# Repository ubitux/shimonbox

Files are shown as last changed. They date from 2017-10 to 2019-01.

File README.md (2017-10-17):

ShimonBox
=========

ShimonBox is an [OpenSCAD][openscad] project aiming at providing
semi-automatically generated 3D printable cases for development boards.

See [pkh.me introduction blog post][blog-post] for more information.

[openscad]: http://www.openscad.org
[blog-post]: http://blog.pkh.me/p/24-making-development-board-cases-with-shimonbox.html

Supported boards
----------------

| Board name | Preview |
| --- | --- |
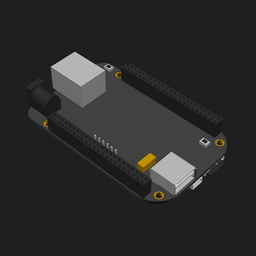
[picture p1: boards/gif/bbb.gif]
| [BeagleBone Black](boards/bbb.scad) |  |
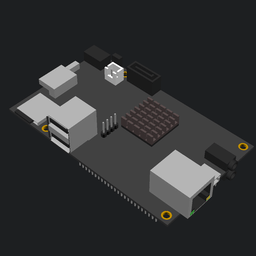
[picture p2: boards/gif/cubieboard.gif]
Cubieboard
| [Cubieboard](boards/cubieboard.scad) |  |
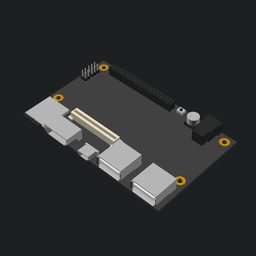
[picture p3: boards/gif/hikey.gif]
Hikey
| [Hikey (LeMaker)](boards/hikey.scad) |  |
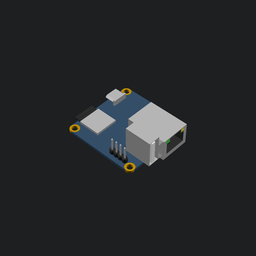
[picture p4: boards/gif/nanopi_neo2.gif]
NanoPi Neo 2
| [NanoPi Neo 2](boards/nanopi_neo2.scad) |  |
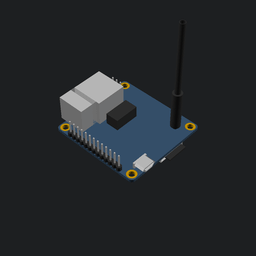
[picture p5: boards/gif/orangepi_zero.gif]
Orange Pi Zero
| [Orange Pi Zero](boards/orangepi_zero.scad)  |   |
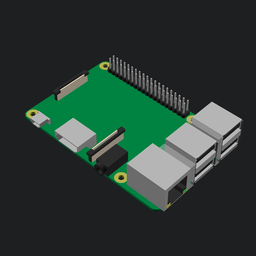
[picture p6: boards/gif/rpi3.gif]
| [Raspberry Pi 3](boards/rpi3.scad) |  |

Corresponding cases
-------------------

| Board name | Preview | Status |
| --- | --- | --- |
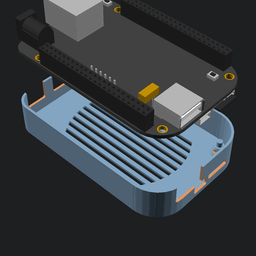
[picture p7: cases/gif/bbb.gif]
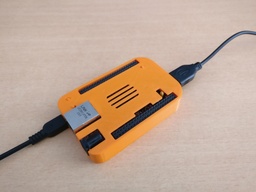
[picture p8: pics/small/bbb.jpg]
| [BeagleBone Black](cases/bbb.scad) |  | [VERIFIED](pics/bbb.jpg):<br /> |
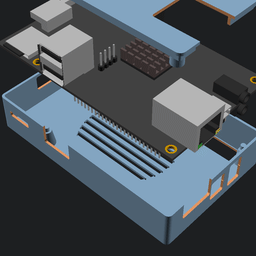
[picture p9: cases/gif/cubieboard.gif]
Cubieboard
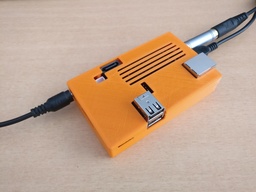
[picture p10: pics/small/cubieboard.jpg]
Cubieboard
| [Cubieboard](cases/cubieboard.scad) |  | [VERIFIED](pics/cubieboard.jpg):<br /> |
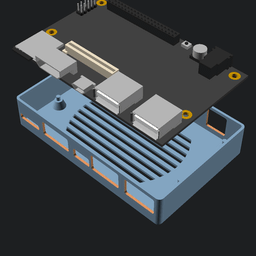
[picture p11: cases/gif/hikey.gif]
Hikey
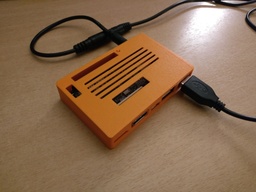
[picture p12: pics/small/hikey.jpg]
Hikey
| [Hikey (LeMaker)](cases/hikey.scad) |  | [VERIFIED](pics/hikey.jpg):<br /> |
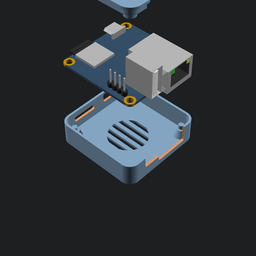
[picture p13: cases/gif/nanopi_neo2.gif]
NanoPi Neo 2
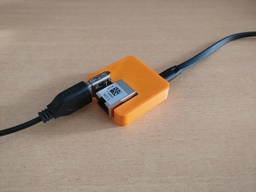
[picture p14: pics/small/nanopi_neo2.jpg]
NanoPi Neo 2
| [NanoPi Neo 2](cases/nanopi_neo2.scad) |  | [VERIFIED](pics/nanopi_neo2.jpg):<br /> |
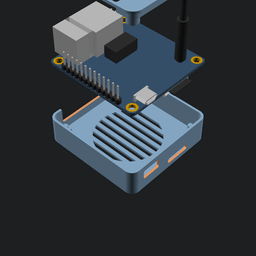
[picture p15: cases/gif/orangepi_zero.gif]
Orange Pi Zero
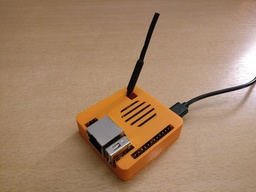
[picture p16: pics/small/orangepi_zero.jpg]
Orange Pi Zero
| [Orange Pi Zero](cases/orangepi_zero.scad) |  | [VERIFIED](pics/orangepi_zero.jpg):<br /> |
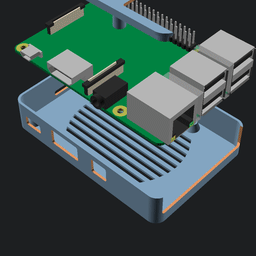
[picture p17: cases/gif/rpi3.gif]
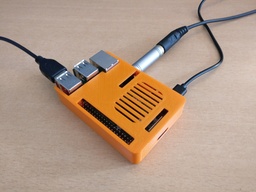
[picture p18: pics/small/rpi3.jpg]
| [Raspberry Pi 3](cases/rpi3.scad) |  | [VERIFIED](pics/rpi3.jpg):<br /> |

Usage
-----

To make all the `.stl` files, run `make`. The resulting files will be found in
the [cases/](cases) directory.

If you're looking at building individual parts, you can use `make
cases/<board>-<part>.stl` where `<board>` is the board name and `<part>` is the
part you want to build (`bottom`, `top`, or `button`).

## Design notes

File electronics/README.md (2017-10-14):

| Category | Preview |
| --- | --- |
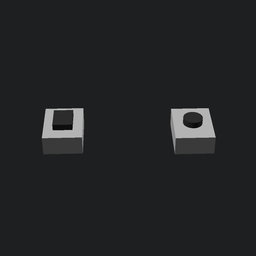
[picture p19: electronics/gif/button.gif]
Buttons
| Buttons |  |
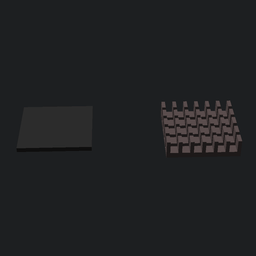
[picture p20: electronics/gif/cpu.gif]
CPU
| CPU |  |
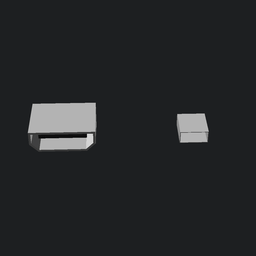
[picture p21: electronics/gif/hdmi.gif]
HDMI
| HDMI |  |
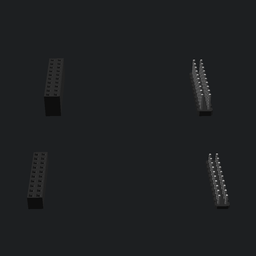
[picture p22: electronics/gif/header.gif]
headers
| Pin and Female Headers  |  |
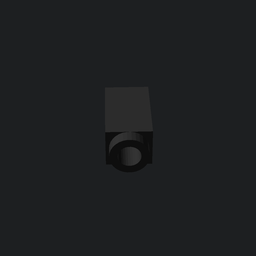
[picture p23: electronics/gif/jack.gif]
jack
| Jack |  |
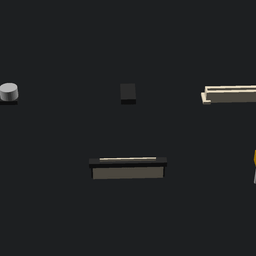
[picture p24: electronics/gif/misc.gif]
Misc
| Miscleanous stuff |  |
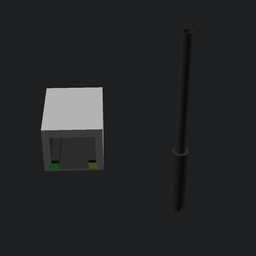
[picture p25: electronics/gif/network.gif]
Network
| Network |   |
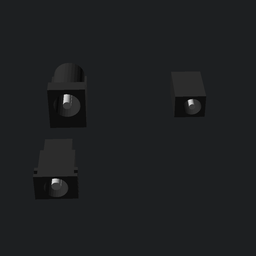
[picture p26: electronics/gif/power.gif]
Power
| Power |  |
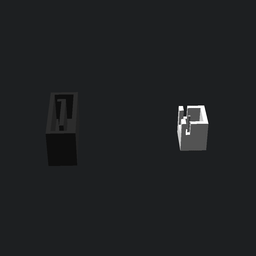
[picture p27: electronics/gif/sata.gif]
SATA
| SATA |  |
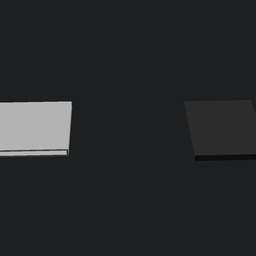
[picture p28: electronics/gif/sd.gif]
| SD |  |
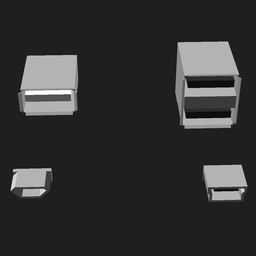
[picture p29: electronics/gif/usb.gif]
USB
| USB |  |

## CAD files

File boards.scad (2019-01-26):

// Copyright (c) 2017 Clément Bœsch <u pkh.me>
//
// Permission to use, copy, modify, and distribute this software for any
// purpose with or without fee is hereby granted, provided that the above
// copyright notice and this permission notice appear in all copies.
//
// THE SOFTWARE IS PROVIDED "AS IS" AND THE AUTHOR DISCLAIMS ALL WARRANTIES
// WITH REGARD TO THIS SOFTWARE INCLUDING ALL IMPLIED WARRANTIES OF
// MERCHANTABILITY AND FITNESS. IN NO EVENT SHALL THE AUTHOR BE LIABLE FOR
// ANY SPECIAL, DIRECT, INDIRECT, OR CONSEQUENTIAL DAMAGES OR ANY DAMAGES
// WHATSOEVER RESULTING FROM LOSS OF USE, DATA OR PROFITS, WHETHER IN AN
// ACTION OF CONTRACT, NEGLIGENCE OR OTHER TORTIOUS ACTION, ARISING OUT OF
// OR IN CONNECTION WITH THE USE OR PERFORMANCE OF THIS SOFTWARE.

include <globals.scad>

use <utils.scad>

use <boards/bbb.scad>
use <boards/cubieboard.scad>
use <boards/hikey.scad>
use <boards/nanopi_neo2.scad>
use <boards/orangepi_zero.scad>
use <boards/rpi3.scad>
use <boards/wemos_esp8266.scad>

boards = [
    ["bbb",             beaglebone_black_info()],
    ["cubieboard",      cubieboard_info()],
    ["hikey",           hikey_info()],
    ["nanopi_neo2",     nanopi_neo2_info()],
    ["orangepi_zero",   orangepi_zero_info()],
    ["rpi3",            raspberry_pi_3_info()],
    ["wemos_esp8266",   wemos_esp8266_info()],
];

module boards_get_plate_2d(id) {
    filter(id) {
        beaglebone_black_plate_2d();
        cubieboard_plate_2d();
        hikey_plate_2d();
        nanopi_neo2_plate_2d();
        orangepi_zero_plate_2d();
        raspberry_pi_3_plate_2d();
        wemos_esp8266_plate_2d();
    }
}

module boards_get_board(id) {
    filter(id) {
        beaglebone_black();
        cubieboard();
        hikey();
        nanopi_neo2();
        orangepi_zero();
        raspberry_pi_3();
        wemos_esp8266();
    }
}

function boards_get_id(name) = search([name], boards)[0];
function boards_get_info(id) = boards[id][1];

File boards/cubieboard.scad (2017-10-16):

// Copyright (c) 2017 Clément Bœsch <u pkh.me>
//
// Permission to use, copy, modify, and distribute this software for any
// purpose with or without fee is hereby granted, provided that the above
// copyright notice and this permission notice appear in all copies.
//
// THE SOFTWARE IS PROVIDED "AS IS" AND THE AUTHOR DISCLAIMS ALL WARRANTIES
// WITH REGARD TO THIS SOFTWARE INCLUDING ALL IMPLIED WARRANTIES OF
// MERCHANTABILITY AND FITNESS. IN NO EVENT SHALL THE AUTHOR BE LIABLE FOR
// ANY SPECIAL, DIRECT, INDIRECT, OR CONSEQUENTIAL DAMAGES OR ANY DAMAGES
// WHATSOEVER RESULTING FROM LOSS OF USE, DATA OR PROFITS, WHETHER IN AN
// ACTION OF CONTRACT, NEGLIGENCE OR OTHER TORTIOUS ACTION, ARISING OUT OF
// OR IN CONNECTION WITH THE USE OR PERFORMANCE OF THIS SOFTWARE.

include <../globals.scad>

use <../case.scad>
use <../utils.scad>
use <../electronics/button.scad>
use <../electronics/cpu.scad>
use <../electronics/hdmi.scad>
use <../electronics/header.scad>
use <../electronics/jack.scad>
use <../electronics/misc.scad>
use <../electronics/network.scad>
use <../electronics/power.scad>
use <../electronics/sata.scad>
use <../electronics/sd.scad>
use <../electronics/usb.scad>


board_dim = [100, 60, 1.25];


/* Plate holes */
hole_d = 3;
hole_orig = [board_dim[0], board_dim[1]] * -.5;
ring_off = 1.5;
hole_pad = 3.5;
hole_pad_t = [1,-1]*hole_pad;
holes_pos = [for (y=hole_pad_t+[   0, board_dim[1]],
                  x=hole_pad_t+[19.5, board_dim[0]]) hole_orig + [x, y]];


/* Components bounding box dimensions */
cpu_dim         = [   19,   19, 1.25];
cpurad_dim      = [   19,   19,    5];
ethernet_dim    = [   21,   16, 13.5];
fel_dim         = [  3.5,    7,  3.5];
gpio_dim        = [   50,    6,    6];
hdmi_dim        = [11.25,   15,    6];
ir_dim          = [  3.5,    5,    7];
jack_dim        = [   14,  6.5,    5];
microsdcard_dim = [   15,   11,    1];
microsdslot_dim = [14.75,   15,    2];
otg_dim         = [    9,    7,    4];
power_dim       = [   12,  7.5,    6];
powerbtn_dim    = [  3.5,    7,  3.5];
sata_5v_dim     = [  7.5,    6,  7.5];
sata_data_dim   = [   17,  6.5,    9];
serial_dim      = [10.25,  2.5,  8.5];
usbx2_dim       = [ 17.5, 14.5,   16];

pwrhdmi_dim     = [3.5, 2, 3.5]; // cleanup box

module cubieboard_plate_2d() {
    plate_2d(board_dim[0], board_dim[1]);
}

comp_info = [
    /* info function        box dimensions   comp-corner rotate  board-corner    position  */
    [button_drill_info(),   fel_dim,         [-1,-1, 1], [0,1,0], [ 1,-1,-1], [   0,26.5,   0]],
    [button_drill_info(),   powerbtn_dim,    [-1, 1, 1], [0,3,0], [-1, 1, 1], [ -.5, -16,   0]],
    [cpu_info(),            cpu_dim,         [-1,-1,-1], [0,0,0], [-1,-1, 1], [47.5,  28,   0]],
    [cpurad_info(),         cpurad_dim,      [-1,-1,-1], [0,0,0], [-1,-1, 1], [47.5,  28,1.25]],
    [ethernet_info(),       ethernet_dim,    [ 1,-1,-1], [0,0,0], [ 1,-1, 1], [   4,   8,   0]],
    [hdmi_info(),           hdmi_dim,        [ 1, 1,-1], [0,0,2], [-1,-1, 1], [ -.5,  20,   0]],
    [ir_info(),             ir_dim,          [-1,-1,-1], [0,0,3], [-1, 1, 1], [13.5,  .5,   0]],
    [jack_info(),           jack_dim,        [ 1,-1, 1], [0,0,0], [ 1,-1,-1], [   2,  39,   0]], // bottom
    [jack_info(),           jack_dim,        [ 1,-1,-1], [0,0,0], [ 1,-1, 1], [   2,  39,   0]], // top
    [microsdcard_info(),    microsdcard_dim, [ 1,-1,-1], [0,0,3], [-1,-1, 1], [   5, -.5,   1]],
    [microsdslot_info(),    microsdslot_dim, [ 1,-1,-1], [0,0,3], [-1,-1, 1], [   4,1.75,   0]],
    [miniusb_info(),        otg_dim,         [ 1,-1,-1], [0,0,0], [ 1,-1, 1], [   1,26.5,   0]],
    [pin_header_info(),     gpio_dim,        [ 1, 1,-1], [2,0,0], [ 1,-1,-1], [  -6,  .5,   0]],
    [pin_header_info(),     gpio_dim,        [ 1,-1,-1], [2,0,0], [ 1, 1,-1], [  -6, -.5,   0]],
    [pin_header_info(),     serial_dim,      [-1, 1,-1], [0,0,1], [-1,-1, 1], [44.5,  17,   0]],
    [power_cubie_info(),    power_dim,       [ 1,-1,-1], [0,0,2], [-1, 1, 1], [   0,-2.5,   0]],
    [sata_5v_info(),        sata_5v_dim,     [-1,-1,-1], [0,0,0], [-1,-1, 1], [  18,  47,   0]],
    [sata_data_info(),      sata_data_dim,   [ 1,-1,-1], [0,0,2], [-1, 1, 1], [  27,   0,   0]],
    [usbx2_info(),          usbx2_dim,       [ 1,-1,-1], [0,0,3], [-1,-1, 1], [  29, -.5,   0]],

    [unknown_drill_info(),  pwrhdmi_dim,     [ 1, 1,-1], [0,0,2], [-1,-1, 1], [ -.5,  35,   0]],
];

module cubieboard() {
    // TODO: ring $fn=8
    extrude_plate(board_dim[2], holes_pos, hole_d, ring_off)
        cubieboard_plate_2d();

    set_components(board_dim, comp_info) {
        button(dim=fel_dim);
        button(dim=powerbtn_dim);
        cpu(dim=cpu_dim);
        cpurad(dim=cpurad_dim);
        ethernet(dim=ethernet_dim);
        hdmi(dim=hdmi_dim);
        ir(dim=ir_dim);
        jack(dim=jack_dim);
        jack(dim=jack_dim);
        microsdcard(dim=microsdcard_dim);
        microsdslot(dim=microsdslot_dim);
        miniusb(dim=otg_dim);
        pin_header_pitch200(dim=gpio_dim, n=24, m=2);
        pin_header_pitch200(dim=gpio_dim, n=24, m=2);
        pin_header_pitch254(dim=serial_dim, n=4, m=1);
        power_cubie(dim=power_dim);
        sata_5v(dim=sata_5v_dim);
        sata_data(dim=sata_data_dim);
        usbx2(dim=usbx2_dim);

        %cube(pwrhdmi_dim, center=true);
    }
}

function cubieboard_info() = [
    ["board_dim",  board_dim],
    ["components", comp_info],
    ["holes_d",    hole_d],
    ["holes_pos",  holes_pos],
];

demo_board(board_dim) {
    cubieboard();
    *#bounding_box(board_dim, comp_info);
}

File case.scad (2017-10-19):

// Copyright (c) 2017 Clément Bœsch <u pkh.me>
//
// Permission to use, copy, modify, and distribute this software for any
// purpose with or without fee is hereby granted, provided that the above
// copyright notice and this permission notice appear in all copies.
//
// THE SOFTWARE IS PROVIDED "AS IS" AND THE AUTHOR DISCLAIMS ALL WARRANTIES
// WITH REGARD TO THIS SOFTWARE INCLUDING ALL IMPLIED WARRANTIES OF
// MERCHANTABILITY AND FITNESS. IN NO EVENT SHALL THE AUTHOR BE LIABLE FOR
// ANY SPECIAL, DIRECT, INDIRECT, OR CONSEQUENTIAL DAMAGES OR ANY DAMAGES
// WHATSOEVER RESULTING FROM LOSS OF USE, DATA OR PROFITS, WHETHER IN AN
// ACTION OF CONTRACT, NEGLIGENCE OR OTHER TORTIOUS ACTION, ARISING OUT OF
// OR IN CONNECTION WITH THE USE OR PERFORMANCE OF THIS SOFTWARE.

include <globals.scad>
include <boards.scad>
use <utils.scad>

case_thickness  = 1.2;
breath_padding  = 1;
contact_padding = .2;

/* Centered top of the buttons looking at the sky, and their dimensions */
function _get_buttons_pushers_pos_dim(board_dim, cfg, info) = [
    let(comp_info_list = map_get(info, "components"))

    for (comp_info = comp_info_list)
        let(meta         = comp_info[0],
            dim          = comp_info[1],
            corner_comp  = comp_info[2],
            rot          = comp_info[3],
            corner_board = comp_info[4],
            position     = comp_info[5],
            category     = map_get(meta, "category"))

        if (category == "button" && [rot[0], rot[1]] == [0, 0])
            let(rz             = comp_info[3][2] * 90,
                rotm           = [[cos(rz),sin(rz),0], [-sin(rz),cos(rz),0], [0,0,1]],
                corner_pos     = pmul(corner_comp, dim) * -.5,
                postrotate_pos = corner_pos * rotm,
                board_pos      = pmul(corner_board, board_dim) * .5,
                centered_pos   = postrotate_pos + position + board_pos,
                pos            = centered_pos + [0, 0, dim[2]/2])

            [pos, dim]
];

module _vents(vents, w=2.1) {
    if (vents != []) {
        dim = map_get(vents, "dim");
        pos = map_get(vents, "pos");

        length = dim[1];
        n_segments = floor(length / w);
        n_vents    = ceil(n_segments / 2);
        n_segwalls = n_segments - n_vents;
        n_walls    = n_segwalls - (n_segwalls == n_vents ? 1 : 0);
        off        = (length - (n_vents+n_walls)*w) / 2;
        start      = -length/2 + off + w/2;
        translate(pos) {
            intersection() {
                circle(d=max(dim), center=true);
                for (i = [0:n_vents-1])
                    translate([0, start + i*w*2])
                        square([dim[0], w], center=true);
            }
        }
    }
}

module _case_plate_2d(case_id) {
    offset(r=case_thickness + breath_padding + _delta)
        boards_get_plate_2d(case_id);
}

module _case_top(case_id, cfg, info, z_offset, buttons_pos_dim) {
    top_border_height = 3; // XXX: maybe auto to (max_z+bp)/2 or /3?

    board_dim = map_get(info, "board_dim");
    comp_info = map_get(info, "components");
    holes_d   = map_get(info, "holes_d");
    holes_pos = map_get(info, "holes_pos");

    vents = map_get(map_get(cfg, "vents"), "top");

    difference() {
        union() {
            // plate
            linear_extrude(height=case_thickness, center=true, convexity=2) {
                difference() {
                    _case_plate_2d(case_id);
                    _vents(vents);
                }
            }

            // borders
            translate([0, 0, -case_thickness/2 - top_border_height]) {
                linear_extrude(height=top_border_height, convexity=2) {
                    difference() {
                        offset(r=breath_padding - contact_padding)
                            boards_get_plate_2d(case_id);
                        offset(r=breath_padding - contact_padding - case_thickness)
                            boards_get_plate_2d(case_id);
                    }
                }
            }

            // board carriers clippers
            h = map_get(cfg, "max_z") + breath_padding - contact_padding;
            for(pos = holes_pos) {
                translate([pos[0], pos[1], -(h+case_thickness)/2]) {
                    difference() {
                        cylinder(h=h, d=holes_d+2, center=true);
                        cylinder(h=h+_delta, d=holes_d, center=true);
                    }
                }
            }

            // button pushers borders
            for (button_pos_dim = buttons_pos_dim) {
                button_pos = button_pos_dim[0];
                button_dim = button_pos_dim[1];
                h = top_border_height;
                d = _get_button_pusher_d(button_dim) + case_thickness*2;
                translate([button_pos[0], button_pos[1], -case_thickness/2-h])
                    cylinder(h=h, d=d);
            }
        }

        translate([0, 0, -z_offset])
            bounding_box(board_dim, comp_info, breath_padding);

        for (button_pos_dim = buttons_pos_dim) {
            button_pos = button_pos_dim[0];
            button_dim = button_pos_dim[1];
            h = top_border_height + case_thickness + _delta;
            d = _get_button_pusher_d(button_dim) + contact_padding;
            translate([button_pos[0], button_pos[1], case_thickness/2-h+_delta/2])
                cylinder(h=h, d=d);
        }
    }
}

module _case_bottom(case_id, cfg, info, z_offset, bottom_border_h) {
    board_dim = map_get(info, "board_dim");
    comp_info = map_get(info, "components");
    holes_d   = map_get(info, "holes_d");
    holes_pos = map_get(info, "holes_pos");

    vents = map_get(map_get(cfg, "vents"), "bottom");

    difference() {
        union() {
            // plate
            linear_extrude(height=case_thickness, center=true) {
                difference() {
                    _case_plate_2d(case_id);
                    _vents(vents);
                }
            }

            // borders
            translate([0, 0, case_thickness/2]) {
                linear_extrude(height=bottom_border_h, convexity=2) {
                    difference() {
                        _case_plate_2d(case_id);
                        offset(r=breath_padding + _delta)
                            boards_get_plate_2d(case_id);
                    }
                }
            }

            // board carriers
            carriers_base_h = -z_offset - board_dim[2]/2 - case_thickness/2;
            for(pos = holes_pos) {
                translate([pos[0], pos[1], case_thickness/2]) {
                    l1 = carriers_base_h;
                    l  = carriers_base_h + board_dim[2] + 1;
                    w0 = holes_d/2 - contact_padding;
                    w1 = w0 + 1;
                    w2 = w0 + 2.5;
                    rotate_extrude()
                        polygon([[0, 0], [w2, 0], [w1, l1], [w0, l1], [w0, l], [0, l]]);
                }
            }
        }
        translate([0, 0, -z_offset])
            bounding_box(board_dim, comp_info, breath_padding);
    }

}

module _button_pushers(board_dim, cfg, info, buttons_pos_dim) {
    for (button_pos_dim = buttons_pos_dim) {
        button_pos = button_pos_dim[0];
        button_dim = button_pos_dim[1];
        translate(button_pos) {
            h = _get_button_pusher_base_h(cfg) - button_dim[2];
            d = _get_button_pusher_d(button_dim);
            cylinder(d=d, h=d/2);
            cylinder(d=2*d/3, h=h);
        }
    }
}

function _get_button_pusher_base_h(info) =
    map_get(info, "max_z") + breath_padding + case_thickness + 1;

function _get_button_pusher_d(button_dim) =
    max(min(button_dim[0], button_dim[1]), 3.5);

module case(name, cfg, mode="demo") {
    case_id = boards_get_id(name);
    info = boards_get_info(case_id);
    comp_info = map_get(info, "components");

    // TODO: find min_z and max_z based on the comp list when not provided
    min_z = map_get(cfg, "min_z");
    max_z = map_get(cfg, "max_z");

    board_dim = map_get(info, "board_dim");
    board_h = board_dim[2];

    bottom_border_h = min_z + max_z + breath_padding*2 + board_h;

    z_offset_base   = board_h/2 + breath_padding + case_thickness/2;
    z_offset_bottom = -z_offset_base - min_z;
    z_offset_top    =  z_offset_base + max_z;

    case_pos_bottom = [0, 0, z_offset_bottom];
    case_pos_top    = [0, 0, z_offset_top];

    buttons_pos_dim = _get_buttons_pushers_pos_dim(board_dim, cfg, info);
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

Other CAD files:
cases/cubieboard.scad
boards/bbb.scad
boards/hikey.scad
boards/nanopi_neo2.scad
boards/orangepi_zero.scad
boards/rpi3.scad
boards/wemos_esp8266.scad
cases/bbb.scad
cases/hikey.scad
cases/nanopi_neo2.scad
cases/orangepi_zero.scad
cases/rpi3.scad
cases/wemos_esp8266.scad
electronics/_internal.scad
electronics/button.scad
electronics/cpu.scad
electronics/hdmi.scad
electronics/header.scad
electronics/jack.scad
electronics/misc.scad
electronics/network.scad
electronics/power.scad
electronics/sata.scad
electronics/sd.scad
electronics/usb.scad
globals.scad
utils.scad

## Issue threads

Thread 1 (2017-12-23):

Add Pine64 board support

dragetd, 2017-12-23:
I am working on adding the specs for the pine64 board.

ubitux, 2017-12-25:
Cool, I don't have that one :)

I've let this project on hold due to other projects taking over, and also because I'm waiting for kernel 4.15 before I can migrate my current odroid-c2 to the nanopi neo 2 (they need 4.15 for the ethernet support) and then design its board.

dragetd, 2017-12-25:
I have an odroid Zero, RPi 1, RPi Zero and eventually a few others to add. :)

Tho kind of busy with things, might take a little before I get to all of these. And I am still wondering if things could be simplified a little.

ubitux, 2017-12-25:
I have the RPi 1 on my TODO list, not sure how long it will take, please leave it to me ;)

dragetd, 2017-12-26:
Sure, I'll leave the RPi1 to you. :) But I might give pi zero a shot, ok? :)

Concerning the Pine64, this is how far I am right now: https://github.com/dragetd/shimonbox/tree/patch_pine64_b

It still lacks several things:

- [ ] Board color
- [ ] GPIO Header x2
- [ ] Expansion Header
- [ ] LCD/Camera bus
- [ ] (Optional) Reset-Button
- [ ] (Optional) LED holes
- [ ] Picture of printed case

I did print the current version and it worked pretty well. It had very minor asymmetries and the 'worst' thing were the mounting holes slightly off (required some force to insert there). But I corrected these things and it should print just fine. Tho before printing another one, I would like to tackle some of the TODOs.

ubitux, 2017-12-26:
> But I might give pi zero a shot, ok? :)

Sure, I don't have that one

> Board color

see `clr` parameter in `extrude_plate()`

> GPIO Header x2

Female and pin headers in `electronics/header.scad` don't do the trick?

dragetd, 2017-12-26:
Yes it does. I was just too lazy, since I do not need those headers for the case I just printed. :P I am busy with other things… once I got my other projcets sorted, I will continue here. Just thought I could already share the progress. :)

dragetd, 2019-02-27:
Please excuse my radio silence. #life happened. :( I hope I will eventually come back to progressing on this - but if anyone else wants to continue the work, please feel free!

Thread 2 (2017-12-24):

Reduce redudancy when defining boards

dragetd, 2017-12-24:
Hey there,

currently adding one or two more boards. While doing this, I also thought about writing a little doc about how to add new boards.

I noticed that I had to put the board name at several places… like defining the base plate it needs an individual name. Then again I also need to add the board to the top-level file boards.scad.

I did not yet read through all the files completely, thus I do not fully understand why it needs to be defined at so many places. Maybe OpenSCAD has some functions to redcuce the redundancy at some points, thus making it easier to add new ones. When I find more specifig things, I will report back to this issue. :-)

ubitux, 2017-12-25:
The OpenSCAD language is pretty limited unfortunately. I tried my best to reduce the need for redundancy without the use of an external language, but typically modules and functions can not be mapped to each other (like, you can't have a function that points to a module). If you find a way of simplifying further, patches welcome.

Also, shimonbox provides boards and cases and you want to be able to use the board model only, without the case.

I should have written a doc on adding a board yes... so far only the blog post gives an overview (http://blog.pkh.me/p/24-making-development-board-cases-with-shimonbox.html)

Here is a quick & dirty howto:

- create `boards/<board>.scad` following other `.scad` files in the same directory. This `.scad` is directly open-able with openscad.
- if necessary, add the electronic components in `electronics/<xxx>.scad`. The `.scad` files are directly open-able with openscad.
- register the board in `boards.scad` (include of `boards/<board>.scad`, mapping array to the info function, and the 2 modules entries)
- create `cases/<board>.scad` following other `.scad` files in the same directory (this one should be pretty simple). This `.scad` is directly open-able with openscad.
- if your board has button pushers, you want to register it in `cases/Makefile` (`BOARDS_WITH_BUTTON_PUSHERS`)
- `make -j$(nproc) gif` will generate the gif (it may take some time)

Feel free to correct me if I forgot something.

dragetd, 2017-12-26:
Yes, I see why you did many things like you did. And I really agree with you on what you wrote in the blog post: OpenSCAD really needs some dev power to improve on a few things. =/

So I will close this issue.

Concerning the contributing guidelines: Will open a new issue once I got around to writing a first version. :)

Closed 2017-12-26.

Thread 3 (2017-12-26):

Add little notch/groove between bottom/top lid?

dragetd, 2017-12-26:
My first print in #1 fits pretty tightly, since the bottom case flexes a tiny little bit because my PCB holes were ~0.2mm off (fixed in my current branch).

But generally, the top part is just 'resting' on the bottom part. What do you think about adding a little groove around the lip that would click into the bottom part?

I would give it a try to modify the case.scad and use a 0.5mm cylinder + a cut on the bottom side that makes the two halves clip together. Any thoughts on this?

ubitux, 2017-12-26:
Mmh. Have you tried to reduced `contact_padding` in `case.scad`? My printer is pretty cheap, so I had to use a `>0` value for parts that are supposed to touch. It could be made configurable by the user, but since I could test the print only on my printer, some settings might be more appropriate than other for other printers.

dragetd, 2018-01-13:
It fits pretty neatly. But it could have a satisfying *click*. =D

Tho, this idea, just like the others are postponed for me till February. If anyone else wants to have a go before me, feel free!

ubitux, 2018-01-13:
A previous version was actually designed with a complex clicking system. Unfortunately, given how thin the whole box and how precise my printer was, it was meaningless complexity. Basically, it either had no effect in the best case, or distorting the whole thing (because the clip wouldn't fit in the mess the printer did).

dragetd, 2019-02-27:
There are several cases on Thingyverse and elsewehere including a notch to 'click' together pieces. Most recent printers are very much capable of the needed precision.

This would be still a very cool addition. :)

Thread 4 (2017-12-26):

Add CONTRIBUTING.md

dragetd, 2017-12-26:
Issue to track progress on writing a CONTRIBUTING.md :-)
A rough, initial plan has been written by ubitux already in #2 which was:

Here is a quick & dirty howto:

  *  create boards/<board>.scad following other .scad files in the same directory. This .scad is directly open-able with openscad.
  *  if necessary, add the electronic components in electronics/<xxx>.scad. The .scad files are directly open-able with openscad.
  *  register the board in boards.scad (include of boards/<board>.scad, mapping array to the info function, and the 2 modules entries)
  *  create cases/<board>.scad following other .scad files in the same directory (this one should be pretty simple). This .scad is directly open-able with openscad.
  *  if your board has button pushers, you want to register it in cases/Makefile (BOARDS_WITH_BUTTON_PUSHERS)
  *  make -j$(nproc) gif will generate the gif (it may take some time)
  *  edit the .md files to add the necessary entries (board, cases, electronics).
This step could be automatized, but it lacks a description to extract from somewhere. Maybe a // @desc or whatever in the .scad files or whatever could do the trick (extracted with a grep or whatever).

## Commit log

2017-10-14 Add common base code
    [_internal.scad, boards.scad, case.scad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]
2017-10-14 electronics: add initial set of components
    [button.scad, cpu.scad, hdmi.scad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]
2017-10-14 boards: add BeagleBone Black
    [bbb.scad, boards.scad]
2017-10-14 cases: add BeagleBone Black
    [bbb.scad]
2017-10-14 boards: add Cubieboard
    [boards.scad, cubieboard.scad]
2017-10-14 cases: add Cubieboard
    [cubieboard.scad]
2017-10-14 boards: add Hikey (LeMaker)
    [boards.scad, hikey.scad]
2017-10-14 cases: add Hikey (LeMaker)
    [hikey.scad]
2017-10-14 boards: add NanoPi Neo 2
    [boards.scad, nanopi_neo2.scad]
2017-10-14 cases: add NanoPi Neo 2
    [nanopi_neo2.scad]
2017-10-14 boards: add OrangePi Zero
    [boards.scad, orangepi_zero.scad]
2017-10-14 cases: add OrangePi Zero
    [orangepi_zero.scad]
2017-10-14 boards: add Raspberry Pi 3
    [boards.scad, rpi3.scad]
2017-10-14 cases: add Raspberry Pi 3
    [rpi3.scad]
2017-10-15 boards/nanopi_neo2: annotate ethusb_dim as cleanup box
    [nanopi_neo2.scad]
2017-10-15 boards/rpi3: add cleanup boxes to prevent thin sticks
    [rpi3.scad]
2017-10-15 case: remove button pushers debugging code
    [case.scad]
2017-10-15 cases/rpi3: add top vents
    [rpi3.scad]
2017-10-15 cases/cubieboard: add top vents
    [cubieboard.scad]
2017-10-15 boards/rpi3: update gif
2017-10-15 README: mark Raspberry Pi 3 as verified (+pics)
2017-10-15 boards/nanopi_neo2: fix holes positions
    [nanopi_neo2.scad]
2017-10-15 boards/nanopi_neo2: raise microsd card z-position
    [nanopi_neo2.scad]
2017-10-16 boards/cubieboard: add small cleanup box between power btn and hdmi
    [cubieboard.scad, utils.scad]
2017-10-16 cases/cubieboard: raise slightly max_z
    [cubieboard.scad]
2017-10-19 case: replace batches of let() with a single call
    [case.scad]
2019-01-26 electronics: add support for WEMOS 8266 board components
    [cpu.scad, misc.scad, usb.scad]
2019-01-26 boards: add WEMOS 8266 board
    [boards.scad, wemos_esp8266.scad]
2019-01-26 cases: add WEMOS 8266 case
    [wemos_esp8266.scad]
